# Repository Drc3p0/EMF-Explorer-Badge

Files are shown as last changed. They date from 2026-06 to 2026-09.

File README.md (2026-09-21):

# EMF Explorer Badge

Explore the electromagnetic frequencies around you with the [EMF Explorer badge](https://emfexplorer.space), created by Darcy Neal of [SporkLogic](https://sporklogic.com).

The EMF Explorer badge is ideal for soldering workshops at large-scale hacker camps. It aims to provide an accessible tool to inspire curiosity about electronics, and is designed to be easy to assemble by anyone who can wield a soldering iron. Assembly typically takes about one hour. 

## Assembly Instructions
Text, picture, and video assembly guide available at [https://emfexplorer.space/docs.html](https://emfexplorer.space/docs.html) 

## Learn how it Works
Check out the soundwalk videos, learning guides, zine, and frequency monitor at [https://emfexplorer.space/demos.html](https://emfexplorer.space/demos.html)

## Where to Buy
- Buy a ready-to-assemble kit from the [MakerShed](https://www.makershed.com/collections/all/products/emf).
- Order a bare PCB from [OshPark](https://oshpark.com/shared_projects/bRVDS1Pq).
- Learn how to build your own from scratch in [MAKE Magazine, Vol 90](https://www.makershed.com/products/make-magazine-volume-90-print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). 

## Project Info
This repo contains the design files for V1. [Videos of the EMF board in action](https://youtube.com/playlist?list=PLv4aAZ9vybC-C60QNva_aFFxgQik_hsGD&si=QTph-GFbRsYseA82)

## Inspiration
This project was born out of a drive to create accessible learning devices to teach students about electricity.  Some resources that proved invaluable in this process:
- [EMF amplifier workshop from eTextile Summer Camp 2016](https://etextile-summercamp.org/2016/emf/)
- [The legendary Elektrosluch](https://github.com/LOM-instruments/Elektrosluch-3/tree/master/hardware)
- [Gingerbread SVG to KiCad PCB art tool](https://gingerbread.wntr.dev/help.html)

## Images

Current Version



listening to parking meter

listening to electric scooter  

Special edition purple PCB, courtesy of [OshPark](https://oshpark.com), used for workshops at the Open Hardware Summit '24 and dadaLab '24: 


## License

 <p xmlns:cc="http://creativecommons.org/ns#" >This work is licensed under <a href="https://creativecommons.org/licenses/by-nc-sa/4.0/?ref=chooser-v1" target="_blank" rel="license noopener noreferrer" style="display:inline-block;">CC BY-NC-SA 4.0</a></p>

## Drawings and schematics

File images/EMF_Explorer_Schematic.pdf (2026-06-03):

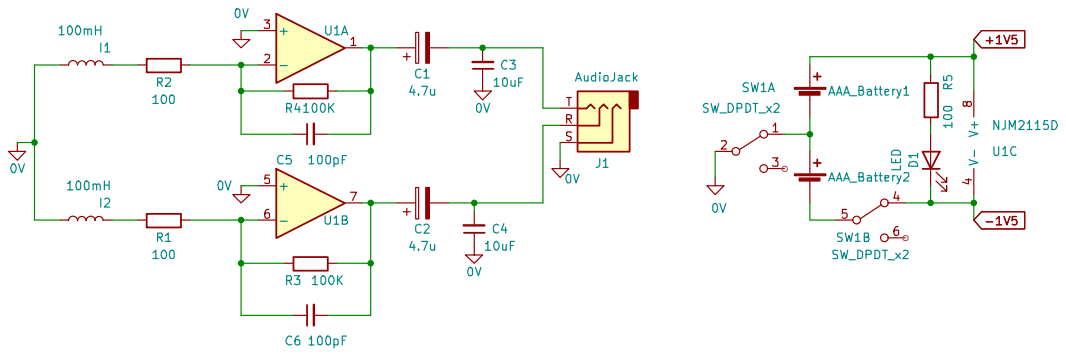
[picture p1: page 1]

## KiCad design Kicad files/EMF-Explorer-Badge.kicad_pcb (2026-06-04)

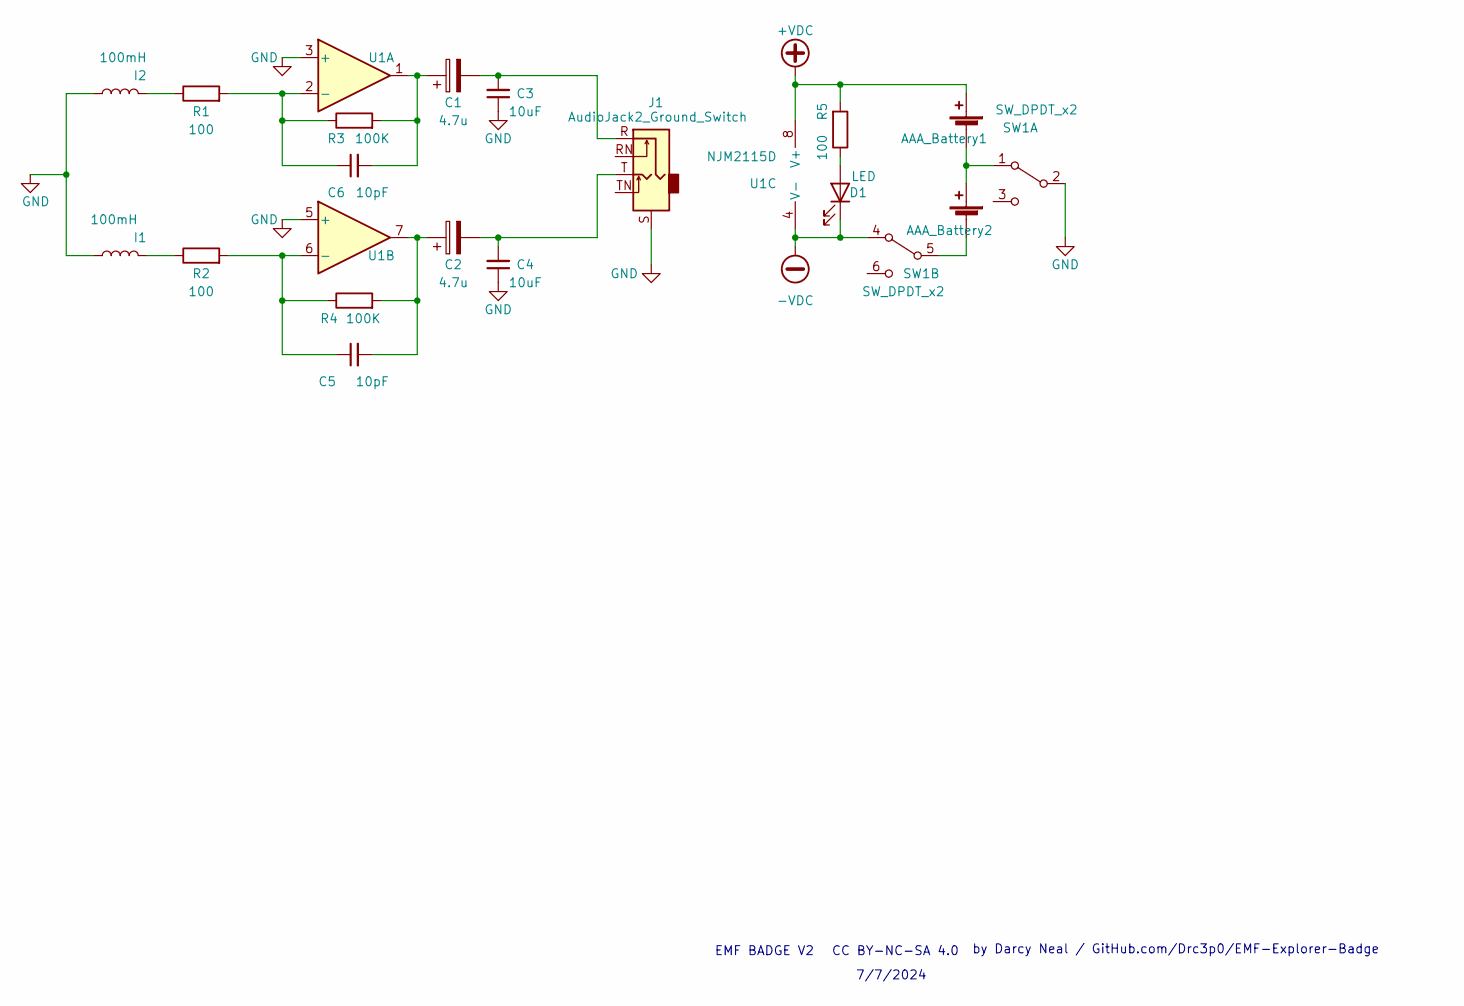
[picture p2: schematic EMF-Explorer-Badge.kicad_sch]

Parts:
AAA_Battery1: Spring_side->; BatteryHolder_Keystone_2466_1xAAA
AAA_Battery2: <-Spring_side; BatteryHolder_Keystone_2466_1xAAA
C1, C2: 4.7u; CP_Radial_D4.0mm_P2.54mm
C3, C4: 10uF; C_Disc_D4.3mm_W1.9mm_P5.00mm
C5, C6: 10pF; C_Disc_D3.4mm_W2.1mm_P2.50mm
D1: LED; LED_D5.0mm_Horizontal_O1.27mm_Z9.0mm
I1, I2: 100mH; Inductor_D5.0mm_Horizontal_O3.81mm_Z9.0mm
J1: AudioJack2_Ground_Switch; Jack_3.5mm_CUI_SJ1-3525N_Horizontal
R1, R2, R5: 100; R_Axial_DIN0207_L6.3mm_D2.5mm_P7.62mm_Horizontal
R3, R4: 100K; R_Axial_DIN0207_L6.3mm_D2.5mm_P7.62mm_Horizontal
SW1: SW_DPDT_x2; DPDT slide switch
U1: NJM2115D; DIP-8_W7.62mm

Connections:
+VDC: AAA_Battery1.1 (+), R5.2, U1.8 (V+)
-VDC: D1.1 (K), SW1.4 (A), U1.4 (V-)
GND: C3.1, C4.1, I1.1, I2.1, J1.S, SW1.2 (B), U1.3 (+), U1.5 (+)
unnamed: AAA_Battery1.2 (-), AAA_Battery2.1 (+), SW1.1 (A)
unnamed: AAA_Battery2.2 (-), SW1.5 (B)
unnamed: C1.1, C6.2, R3.2, U1.1
unnamed: C1.2, C3.2, J1.R
unnamed: C2.1, C5.2, R4.2, U1.7
unnamed: C2.2, C4.2, J1.T
unnamed: D1.2 (A), R5.1
unnamed: I1.2, R2.1
unnamed: I2.2, R1.1
unnamed: C6.1, R1.2, R3.1, U1.2 (-)
unnamed: C5.1, R2.2, R4.1, U1.6 (-)

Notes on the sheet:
EMF BADGE V2
CC BY-NC-SA 4.0
by Darcy Neal / GitHub.com/Drc3p0/EMF-Explorer-Badge
7/7/2024

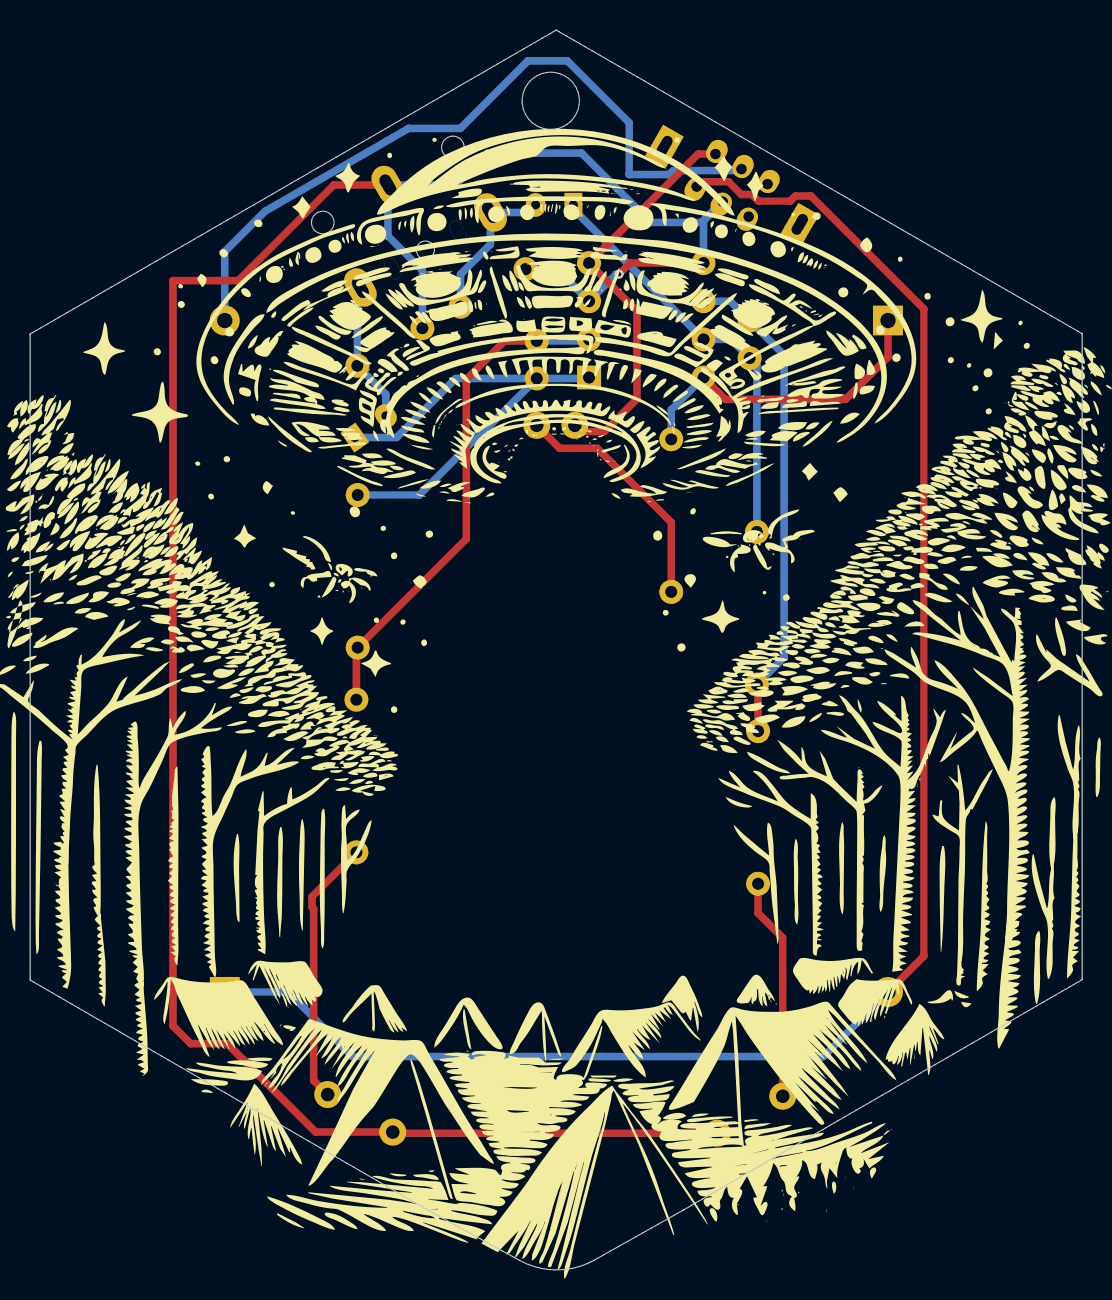
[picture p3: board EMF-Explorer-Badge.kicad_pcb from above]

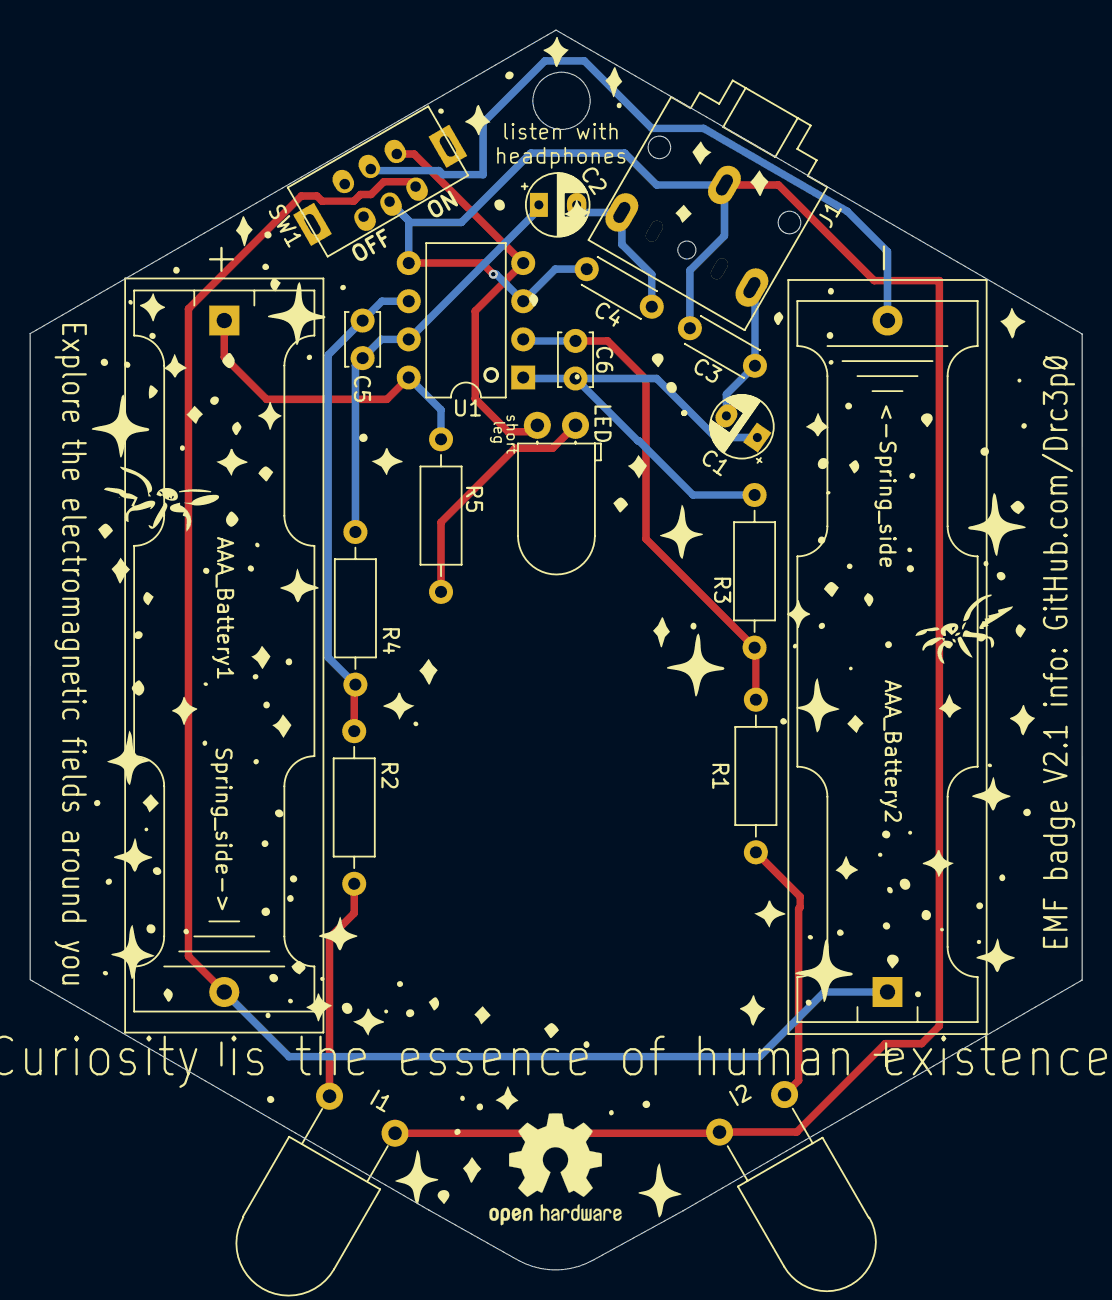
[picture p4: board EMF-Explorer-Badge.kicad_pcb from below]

Board: 2 copper layers, 70.0 x 82.5 mm, 19 parts (19 on the bottom side), 14 nets.

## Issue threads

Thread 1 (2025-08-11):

Text assembly instructions link does not work

n-athan, 2025-08-11:
The link in the readme to https://bit.ly/emf-assembly-guide does not work.
Is there an alternative link?

Drc3p0, 2025-08-14:
The link should redirect to the guide after ~10 seconds. In case that wasn't working, here is a [direct link to the guide](https://docs.google.com/document/d/e/2PACX-1vRfXkslV9D1WnNDk3AQfQqkOoVl3-WPY1uwn4376VyPT9jdpJPXkcEiONuAMLL27d0kzV_tFguxMhDo/pub).

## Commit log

2024-04-26 file cleanup
    [EMFbadge new design-nopFcaps.kicad_sch]
2024-07-19 file uploads
    [EMFbadge new design-nopFcaps.kicad_sch, EMFbadge smallerforKitsNewLayout.kicad_sch]
2025-12-23 Fix assembly guide link and wording in README
    Updated the assembly guide link and corrected the wording for time estimation.
2026-06-04 Kicad 9 file cleanup
    [EMF-Explorer-Badge.kicad_pcb, EMF-Explorer-Badge.kicad_sch, EMFbadge smallerforKitsNewLayout.kicad_pcb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]
2026-09-21 Revise README with updated badge link and guides
    Updated links and assembly guide information for clarity.
